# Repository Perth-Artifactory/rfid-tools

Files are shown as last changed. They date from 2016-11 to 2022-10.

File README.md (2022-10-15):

# doorbot

This has been deprecated in favour of [doorBotCode](https://github.com/Perth-Artifactory/doorBotCode) and [doorbot_1.3](https://github.com/Perth-Artifactory/doorbot_1.3)

-----

RFID based access control for members

The known_cards CSV file contains the hex cardno,member name, and if the card is blocked (True/False)
ie
```
2A0000F001,Random User,
2A0000F002,Non-renewed Member,True
```

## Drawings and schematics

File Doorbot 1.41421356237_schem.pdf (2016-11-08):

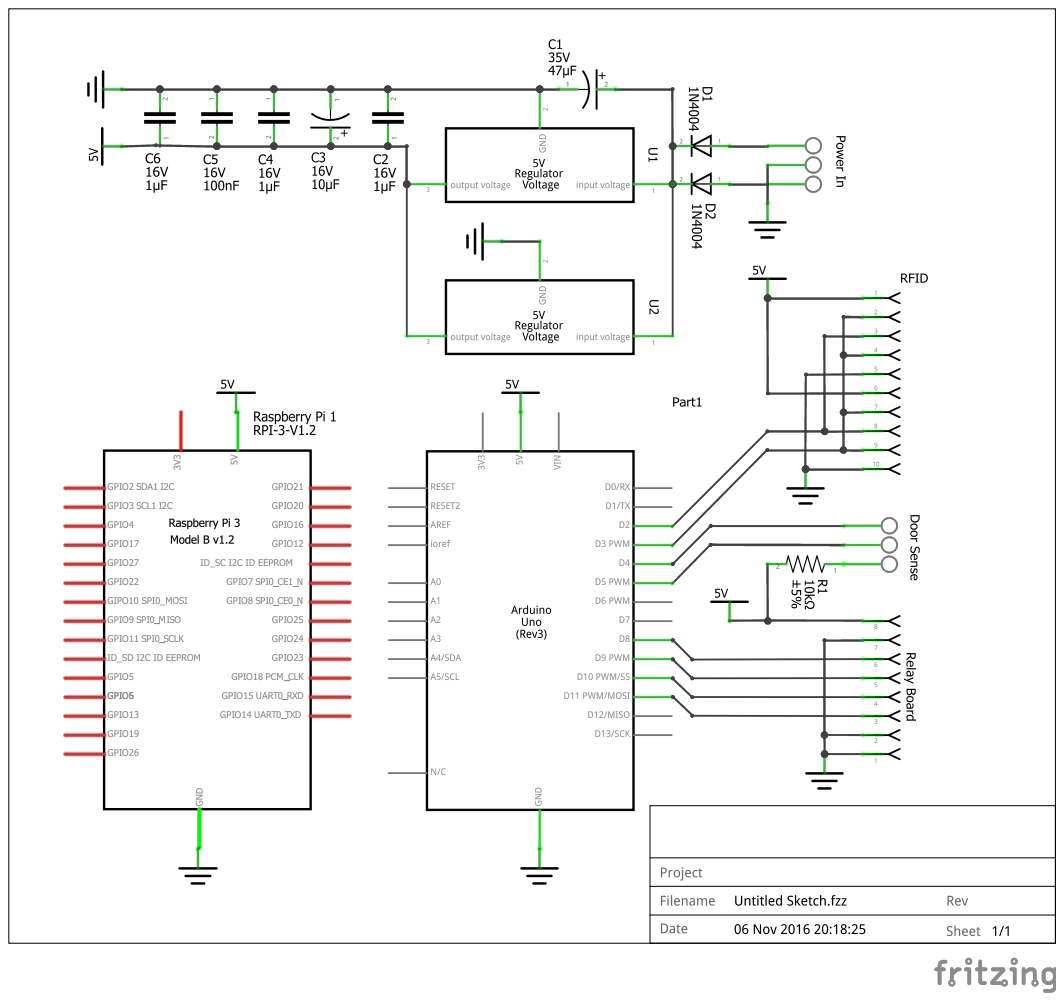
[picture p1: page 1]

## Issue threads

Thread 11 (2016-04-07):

Resurrect Doorbell

Elwell, 2016-04-07:
Doorbell functionality is currently broken

Closed 2024-11-19.

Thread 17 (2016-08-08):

laserbot doesn't display elapsed time

Elwell, 2016-08-08:
Couple of narks -

15:45 < GiantRobot> Laserbot: Jason Kongchouy Logged off BigRed - Total Machine/Laser Time:
15:45 < GiantRobot> Laserbot: 0.0002371

should be on a single line and
time.clock() should probably be time.time() looking at the code

Closed 2016-08-08.

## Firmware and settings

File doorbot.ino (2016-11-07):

/* Artifactory Doorbot - Arduino code to connect to reader
 * and relays.
 *
 * Andrew Elwell <Amdrew.Elwell@gmail.com>
 *  Nov 2016
 */


/* Hardware Config - Via IRC with Lt_Lemming
 *  "I've not done the diagram yet, been too busy building it
 *  RFID is soft serial on Pin 2
 *  button on the box is pulled high on Pin 3 via 10K resistor
 *  Relays are 8, 9, 10 & 11
 *  pins 4 and 5 now wired for door with a common 5v pulled up via 10k resistor
 *  so one should always be high, and if both go low we know something is wrong"
 *
 *  http://gerblook.org/pcb/Vx2DYUBo5HQAF4LjZUSib3
 */


const int RFID = 2;
const int Bell = 3;
const int DoorA = 4;
const int DoorB = 5;
const int Relay1 =  8; // doorstrike
const int Relay2 =  9;
const int Relay3 = 10;
const int Relay4 = 11;


#include <SoftwareSerial.h>
SoftwareSerial rfid(RFID, 13); // RX and TX - RFID is read only so use a 'spare' pin for TX

int doorbell = 1 ;
int doorA = 0;
int doorB = 0;
int i;
int incomingByte = 0;

// checkcard() variables
int  val = 0;
char code[10];
int bytesread = 0;


void setup() {
  rfid.begin(9600);    // start serial to RFID reader
  Serial.begin(9600);  // start serial to Pi

  pinMode(Bell, INPUT);
  pinMode(DoorA, INPUT);
  pinMode(DoorB, INPUT);
  pinMode(Relay1, OUTPUT);
  pinMode(Relay2, OUTPUT);
  pinMode(Relay3, OUTPUT);
  pinMode(Relay4, OUTPUT);

}

void readcard() // ideally this would return value?
{
  if ((val = rfid.read()) == 2)  {
    bytesread = 0;
    while (bytesread < 10) {
      if ( rfid.available() > 0) {
        val = rfid.read();
        if ((val == 2) || (val == 3)) { // if header or stop bytes before the 10 digit reading
          break;                        // stop reading
        }
        code[bytesread] = val;          // add the digit
        bytesread++;                    // ready to read next digit
      }
    }
    if (bytesread == 10) {              // if 10 digit read is complete
      Serial.print("RFID: ");           // who needs stinkin checksums
      Serial.println(code);               // print the TAG code
    }
    bytesread = 0;
  }
}

void loop() {
  if ( Serial.available() > 0) { // got something on serial line
    int inByte = Serial.read();
    // single quotes to get the ASCII value for the character.
    // ie; 'a' = 97, 'b' = 98, and so forth:
    // UPPERCASE: ON, lowercase OFF.
    switch (inByte) {
      case 'A':
        digitalWrite(Relay1, HIGH);
        Serial.print("Relay1: ");
        Serial.println(digitalRead(Relay1));
        break;
      case 'a':
        digitalWrite(Relay1, LOW);
        Serial.print("Relay1: ");
        Serial.println(digitalRead(Relay1));
        break;
      case 'B':
        digitalWrite(Relay2, HIGH);
        Serial.print("Relay2: ");
        Serial.println(digitalRead(Relay2));
        break;
      case 'b':
        digitalWrite(Relay2, LOW);
        Serial.print("Relay2: ");
        Serial.println(digitalRead(Relay2));
        break;
      case 'C':
        digitalWrite(Relay3, HIGH);
        Serial.print("Relay3: ");
        Serial.println(digitalRead(Relay3));
        break;
      case 'c':
        digitalWrite(Relay3, LOW);
        Serial.print("Relay3: ");
        Serial.println(digitalRead(Relay3));
        break;
      case 'D':
        digitalWrite(Relay4, HIGH);
        Serial.print("Relay4: ");
        Serial.println(digitalRead(Relay4));
        break;
      case 'd':
        digitalWrite(Relay4, LOW);
        Serial.print("Relay4: ");
        Serial.println(digitalRead(Relay4));
        break;

      default:
        // return state of all relays and inputs:
        Serial.println(PINB, BIN);
        /* prints say 101011
            maps to Rly 4321
            So, 4,2,1 are on, 3 is off
        */
        Serial.println(PIND, BIN);
    }

  }
  // grab all the digital inputs
  doorbell = digitalRead(Bell);
  doorA = digitalRead(DoorA);
  doorB = digitalRead(DoorB);


  //and process
  readcard();


}

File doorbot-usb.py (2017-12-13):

#!/usr/bin/env python
import sys
from time import gmtime, strftime
import time
import csv
import os
import syslog
import json
import socket

## Where do we store the access cards
cardfile = 'known_cards.csv'


# merged in irker client to notify the IRC channel when door opened
irker_server = ('core', 6659)
target = 'ircs://chat.freenode.net/artifactory'
subsystem = 'Doorbot: '
def connect():
    return socket.create_connection(irker_server)

def send(s, target, message):
    data = {"to": target, "privmsg" : message}
    dump = json.dumps(data)
    if not isinstance(dump, bytes):
        dump = dump.encode('ascii')
    s.sendall(dump)

def irk(message):
    try:
        s = connect()
        send(s, target, subsystem + message)
        s.close()
    except socket.error as e:
        sys.stderr.write("irk: write to server failed: %r\n" % e)

##########

import serial
serial = serial.Serial("/dev/ttyACM0", baudrate=9600)
#serial = serial.Serial("/dev/tty.wchusbserial1410", baudrate=9600, timeout=0)

# Turn on the door relay
time.sleep(5)
serial.write('B')

types = {'6F': 'Card','28':'Fob','1D':'Card', '1C':'Card'}
knowncards = {}

# list of valid cards
with open(cardfile) as csvfile:
    reader = csv.reader(csvfile)
    for row in reader:
        cardhex, person, disabled = row
        knowncards[cardhex] = [person,bool(disabled)]
print knowncards
irk('Started - %d cards loaded' % len(knowncards))
syslog.syslog('Doorbot started')

code = ''
data = ''

def unlock_door():
    serial.write('A')
    time.sleep(5)
    serial.write('a')

while True:
  try:
    while serial.inWaiting() > 0:
      data = serial.readline()
      print data
      if "RFID" in data:
        card = data[-11:-1]
        print card
        prefix = card[0:2]
        cardno = card[2:10]
        if prefix in types:
            tagtype = types[prefix]
        else:
            tagtype = 'RFID'
        cardstr = card,tagtype,int(cardno,16)
        print cardstr
        code = ''
        if knowncards.has_key(card):
            print "KNOWN %s %s presented at door" % (cardstr[1],cardstr[2])
            # Has card been disabled?
            if knowncards[card][1]:
                print "DISABLED: " + knowncards[card][0]
                os.system ("mpg123 -q /home/pi/denied.mp3 &")
                syslog.syslog('DENIED: %s (Card Disabled) %s' % (knowncards[card][0],int(cardno,16)))
	        os.system('echo Sorry This card is disabled %s | festival --tts' % knowncards[card][0])


                irk('\x1b[31m'+knowncards[card][0] +'\x1b[0m denied access')
            else:
                if (knowncards[card][0] == ''):
                    print "ALLOWED UNMAPPED USER"
                    syslog.syslog('ALLOWED: UNMAPPED USER %s' % int(cardno,16))
                    irk('\x1b[33mUnknown User\x1b[0m opened the door')
                else:
                    print "ALLOWED: " + knowncards[card][0]
                    syslog.syslog('ALLOWED: %s %s' % (knowncards[card][0],int(cardno,16)))
                    irk('\x1b[32m' + knowncards[card][0]+ '\x1b[0m opened the door')
                    #cmd="curl -g http://10.60.210.69/entryapi.php?entryname='%s'?time='%s'" % (knowncards[card][0],curtime)
                    #os.system(cmd)
                os.system ("mpg123 -q /home/pi/granted.mp3 &")
		time.sleep(1)
	        #os.system('echo %s | festival --tts' % knowncards[card][0])

                unlock_door()
        else:
            print "UNKNOWN Card/Fob"
            syslog.syslog('DENIED ' + str(cardstr))
            os.system ("mpg123 -q /home/pi/denied.mp3 &")
            irk('\x1b[31mUnknown Card\x1b[0m presented at door')
    #else:
    #    code = code + data
  except (SystemExit, KeyboardInterrupt):
    irk('Shutting Down')
    syslog.syslog('Doorbot shutting down')
    break

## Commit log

2016-04-10 Hack in some card validation
    [known_cards.csv]
2016-04-10 known cards just a sample
    [known_cards.csv]
2016-08-04 Don't crash if unknown card range presented
    [doorbot.py]
2016-08-08 Document what GPIO 18 does
    its the Power line, +5, Tells you if its On or off
    We can detect if the LC turns on, If it doesnt sadfaces occur
2016-08-08 Added GPIO19 for laser tube active
2016-08-08 Don't pull up or down
    From IRC
    Laser on = Low, Laser off = high
    But we dont want to pull it low or high
    The laser will change the state of it
2016-08-08 don't fail on unknown card prefix
    [laserbot.py]
2016-10-05 Added explicit import sys
    Debugging why it failed if unable to irk with sys errror. Turns out
    calling sys.stderr.write isn't possible if called from an Except
    loop.
    [doorbot.py]
2016-11-07 RFID reader and relays now on Arduino, use USB
    Pi uart broke. New hardware installed.
    [doorbot-usb.py, doorbot.ino]
2016-11-08 Schematic and Fritzing board file uploaded.
    [Doorbot 1.41421356237.fzz]
2017-12-13 Reduce the delays for sign relay at start up.
